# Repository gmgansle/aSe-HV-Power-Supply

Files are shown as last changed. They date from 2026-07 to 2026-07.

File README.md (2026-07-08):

# aSe-HV-Power-Supply
This repository includes all of the production files, SOPs, design contraints, and all other important information regarding the High Voltage power supply for use with a Inter-Digitated Electrode-based amorphous Selenium photodetector, or any other semiconducter that can be read using the Cremat CR150 and CR11x Charge Sensitive Preamplifers.

Though the board in it's current state may look complete, it is not. You will need to connect multiple ground pads to their respective pours, amongst other things. Make sure to run a DRC that comes back clean before generating output files.

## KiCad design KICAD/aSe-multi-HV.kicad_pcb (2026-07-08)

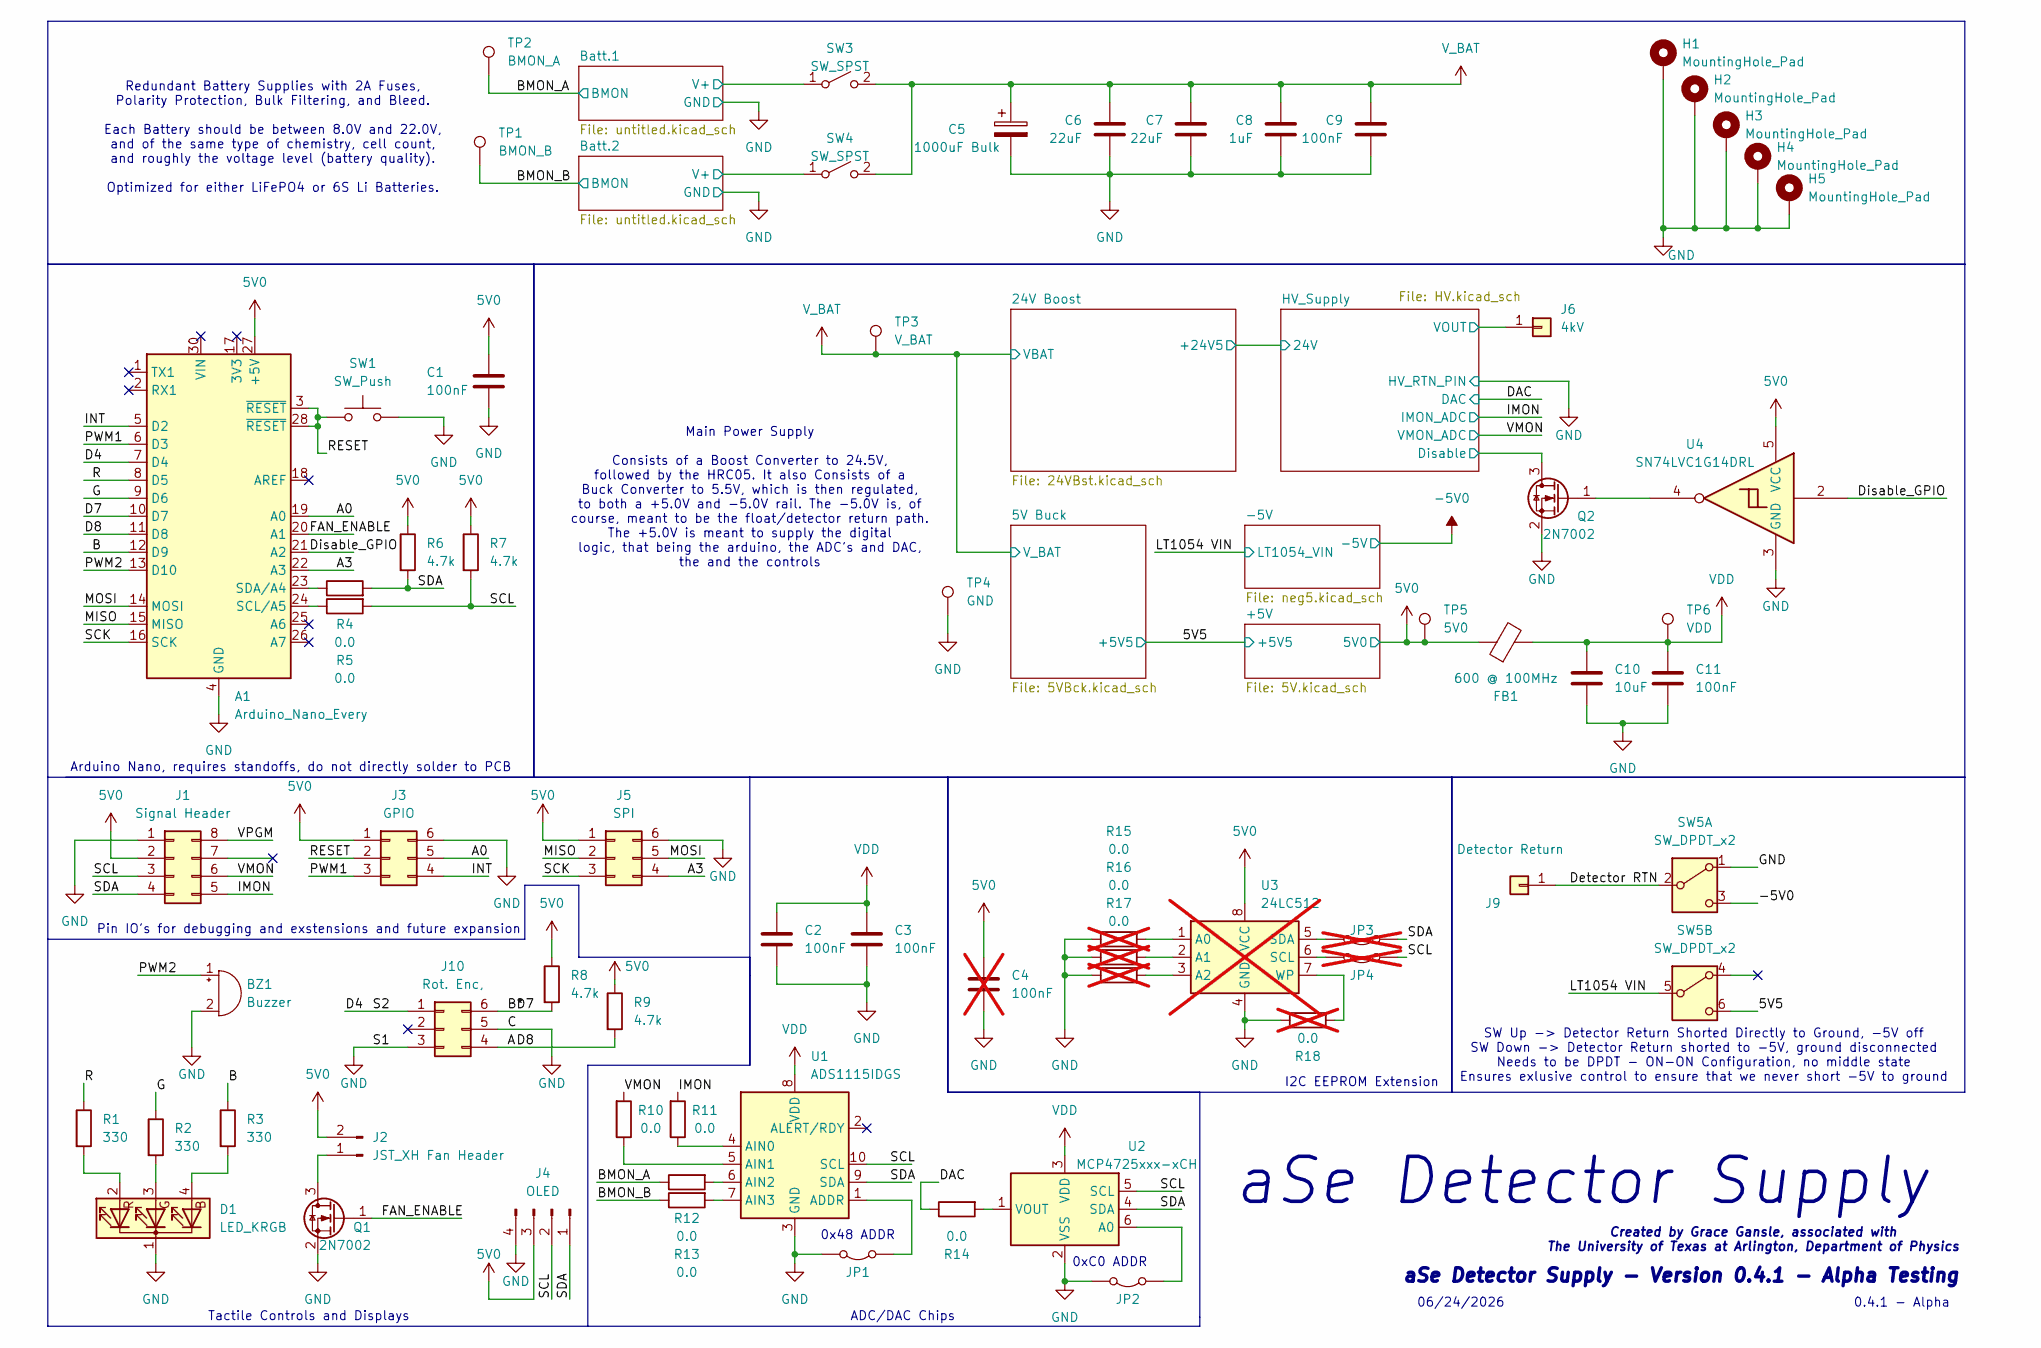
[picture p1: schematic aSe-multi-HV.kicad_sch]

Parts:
A1: Arduino_Nano_Every; Arduino_Nano
BZ1: Buzzer; PinSocket_1x02_P2.54mm_Vertical
C1, C2, C3, C9, C11: 100nF; C_1206_3216Metric_Pad1.33x1.80mm_HandSolder
C4: 100nF; C_1206_3216Metric_Pad1.33x1.80mm_HandSolder; not fitted
C5: 1000uF Bulk; CP_Radial_Tantal_D10.5mm_P5.00mm
C6, C7: 22uF; C_2220_5750Metric_Pad1.97x5.40mm_HandSolder
C8: 1uF; C_1206_3216Metric_Pad1.33x1.80mm_HandSolder
C10: 10uF; C_1206_3216Metric_Pad1.33x1.80mm_HandSolder
D1: LED_KRGB; PinSocket_2x02_P2.54mm_Vertical
FB1: 600 @ 100MHz; L_1206_3216Metric_Pad1.22x1.90mm_HandSolder
H1: MountingHole_Pad; MountingHole_2.2mm_M2_DIN965_Pad_TopBottom
H2, H3, H4, H5: MountingHole_Pad; MountingHole_2.2mm_M2_DIN965_Pad
J1: Signal Header; PinSocket_2x04_P2.54mm_Vertical
J2: JST_XH Fan Header; JST_XH_B2B-XH-AM_1x02_P2.50mm_Vertical
J3: GPIO; PinSocket_2x03_P2.54mm_Vertical
J4: OLED; PinSocket_1x04_P2.54mm_Vertical
J5: SPI; PinSocket_2x03_P2.54mm_Vertical
J6: 4kV; PinSocket_1x01_P2.54mm_Vertical
J9: Detector Return; PinSocket_1x01_P2.54mm_Vertical
J10: Rot. Enc,; PinSocket_2x03_P2.54mm_Vertical
JP1, JP2: SolderJumper-2_P1.3mm_Open_TrianglePad1.0x1.5mm
JP3, JP4: SolderJumper-2_P1.3mm_Open_TrianglePad1.0x1.5mm; not fitted
Q1, Q2: 2N7002; SOT-23
R1, R2, R3: 330; R_1206_3216Metric_Pad1.30x1.75mm_HandSolder
R4, R5, R10, R11, R12, R13, R14: 0.0; R_1206_3216Metric_Pad1.30x1.75mm_HandSolder
R6, R7, R8, R9: 4.7k; R_1206_3216Metric_Pad1.30x1.75mm_HandSolder
R15, R16, R17, R18: 0.0; R_1206_3216Metric_Pad1.30x1.75mm_HandSolder; not fitted
SW1: SW_Push; SW_PUSH_6mm_H5mm
SW3, SW4: SW_SPST; PinSocket_1x02_P2.54mm_Vertical
SW5: SW_DPDT_x2; PinSocket_2x03_P2.54mm_Vertical
TP1: BMON_B; TestPoint_Keystone_5000-5004_Miniature
TP2: BMON_A; TestPoint_Keystone_5000-5004_Miniature
TP3: V_BAT; TestPoint_Keystone_5000-5004_Miniature
TP4: GND; TestPoint_Keystone_5000-5004_Miniature
TP5: 5V0; TestPoint_Keystone_5000-5004_Miniature
TP6: VDD; TestPoint_Keystone_5000-5004_Miniature
U1: ADS1115IDGS; TSSOP-10_3x3mm_P0.5mm
U2: MCP4725xxx-xCH; SOT-23-6
U3: 24LC512; DIP-8_W7.62mm; not fitted
U4: SN74LVC1G14DRL; SOT-553

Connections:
5V0: A1.27 (+5V), C1.1, C4.1, FB1.1, J1.2, J2.2, J3.1, J4.3, J5.1, R6.1, R7.1, R8.1, R9.1, TP5.1 (1_1), U3.8 (VCC), U4.5 (VCC); also elsewhere on the board
-5V0: SW5.3 (C); also elsewhere on the board
/5V5: SW5.6 (C); also elsewhere on the board
/A: A1.11 (D8), J10.4, R9.2
/A0: A1.19 (A0), J3.5
/A3: A1.22 (A3), J5.4
/B: A1.12 (D9), R3.1
/B*: A1.10 (D7), J10.6, R8.2
/BMON_A: R12.1, TP2.1 (1_1); also elsewhere on the board
/BMON_B: R13.1, TP1.1 (1_1); also elsewhere on the board
/Batt.1/V+: SW3.1 (A); also elsewhere on the board
/Batt.2/V+: SW4.1 (A); also elsewhere on the board
/D4: A1.7 (D4), J10.1
/Detector RTN: J9.1 (Pin_1_1), SW5.2 (B)
/Disable_GPIO: A1.21 (A2), U4.2
/FAN_ENABLE: A1.20 (A1), Q1.1 (G)
/G: A1.9 (D6), R2.1
/HV_Supply/!Disable: Q2.3 (D); also elsewhere on the board
/HV_Supply/VOUT: J6.1 (Pin_1_1); also elsewhere on the board
/IMON: J1.5, R11.2; also elsewhere on the board
/INT: A1.5 (D2), J3.4
/LT1054 VIN: SW5.5 (B); also elsewhere on the board
/MISO: A1.15 (MISO), J5.2
/MOSI: A1.14 (MOSI), J5.5
/PWM1: A1.6 (D3), J3.3
/PWM2: A1.13 (D10), BZ1.1 (+)
/R: A1.8 (D5), R1.1
/RESET: A1.3 (~RESET), A1.28 (~RESET), J3.2, SW1.1
/SCK: A1.16 (SCK), J5.3
/SCL: J1.3, J4.2, JP4.1 (A), R5.2, R7.2, U1.10 (SCL), U2.5 (SCL)
/SDA: J1.4, J4.1, JP3.1 (A), R4.2, R6.2, U1.9 (SDA), U2.4 (SDA)
/VMON: J1.6, R10.2; also elsewhere on the board
/VPGM: J1.8, R14.1; also elsewhere on the board
GND: A1.4 (GND), A1.29 (GND), BZ1.2 (-), C1.2, C2.2, C3.2, C4.2, C5.2, C6.2, C7.2, C8.2, C9.2, C10.2, C11.2, D1.1 (K), H1.1 (1_1), H2.1 (1_1), H3.1 (1_1), H4.1 (1_1), H5.1 (1_1), J1.1, J3.6, J4.4, J5.6, J10.3, J10.5, JP1.2 (B), JP2.2 (B), Q1.2 (S), Q2.2 (S), R15.1, R16.1, R17.1, R18.2, SW1.2, SW5.1 (A), TP4.1 (1_1), U1.3 (GND), U2.2 (VSS), U3.4 (GND), U4.3 (GND); also elsewhere on the board
unnamed: A1.24 (SCL/A5), R5.1
unnamed: A1.23 (SDA/A4), R4.1
unnamed: D1.4 (BA), R3.2
unnamed: D1.3 (GA), R2.2
unnamed: D1.2 (RA), R1.2
unnamed: J2.1, Q1.3 (D)
unnamed: JP1.1 (A), U1.1 (ADDR)
unnamed: JP2.1 (A), U2.6 (A0)
unnamed: JP3.2 (B), U3.5 (SDA)
unnamed: JP4.2 (B), U3.6 (SCL)
unnamed: Q2.1 (G), U4.4
unnamed: R11.1, U1.4 (AIN0)
unnamed: R10.1, U1.5 (AIN1)
unnamed: R12.2, U1.6 (AIN2)
unnamed: R13.2, U1.7 (AIN3)
unnamed: R14.2, U2.1 (VOUT)
unnamed: R15.2, U3.1 (A0)
unnamed: R16.2, U3.2 (A1)
unnamed: R17.2, U3.3 (A2)
unnamed: R18.1, U3.7 (WP)
VDD: C2.1, C3.1, C10.1, C11.1, FB1.2, TP6.1 (1_1), U1.8 (VDD), U2.3 (VDD)
V_BAT: C5.1, C6.1, C7.1, C8.1, C9.1, SW3.2 (B), SW4.2 (B), TP3.1 (1_1); also elsewhere on the board

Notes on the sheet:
0x48 ADDR
0.4.1 - Alpha
SW Up -> Detector Return Shorted Directly to Ground, -5V off SW Down -> Detector Return shorted to -5V, ground disconnected Needs to be DPDT - ON-ON Configuration, no middle state Ensures exlusive control to ensure that we never short -5V to ground
Created by Grace Gansle, associated with The University of Texas at Arlington, Department of Physics
ADC/DAC Chips
aSe Detector Supply
Arduino Nano, requires standoffs, do not directly solder to PCB
0xC0 ADDR
Tactile Controls and Displays
06/24/2026
Redundant Battery Supplies with 2A Fuses, Polarity Protection, Bulk Filtering, and Bleed. Each Battery should be between 8.0V and 22.0V, and of the same type of chemistry, cell count, and roughly the voltage level (battery quality). Optimized for either LiFePO4 or 6S Li Batteries.
aSe Detector Supply - Version 0.4.1 - Alpha Testing
I2C EEPROM Extension
Pin IO's for debugging and exstensions and future expansion
Main Power Supply Consists of a Boost Converter to 24.5V, followed by the HRC05. It also Consists of a Buck Converter to 5.5V, which is then regulated, to both a +5.0V and -5.0V rail. The -5.0V is, of course, meant to be the float/detector return path. The +5.0V is meant to supply the digital logic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

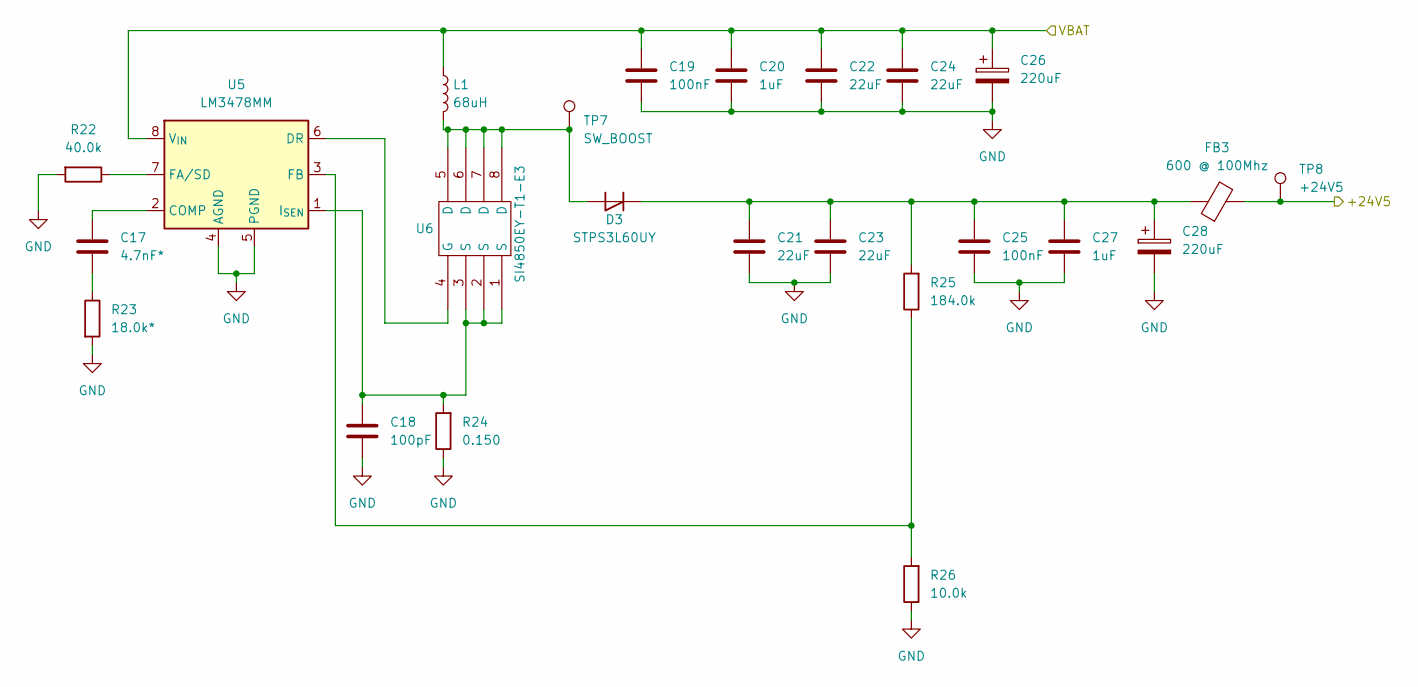
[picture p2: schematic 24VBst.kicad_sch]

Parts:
C17: 4.7nF*; C_1206_3216Metric_Pad1.33x1.80mm_HandSolder
C18: 100pF; C_1206_3216Metric_Pad1.33x1.80mm_HandSolder
C19, C25: 100nF; C_1206_3216Metric_Pad1.33x1.80mm_HandSolder
C20, C27: 1uF; C_1206_3216Metric_Pad1.33x1.80mm_HandSolder
C21, C22, C23, C24: 22uF; C_2220_5750Metric_Pad1.97x5.40mm_HandSolder
C26, C28: 220uF; CP_Radial_Tantal_D10.5mm_P5.00mm
D3: STPS3L60UY; D_SMB-SMC_Universal_Handsoldering
FB3: 600 @ 100Mhz; L_1206_3216Metric_Pad1.22x1.90mm_HandSolder
L1: 68uH; L_Coilcraft_MSS1260-XXX
R22: 40.0k; R_1206_3216Metric_Pad1.30x1.75mm_HandSolder
R23: 18.0k*; R_1206_3216Metric_Pad1.30x1.75mm_HandSolder
R24: 0.150; R_1206_3216Metric_Pad1.30x1.75mm_HandSolder
R25: 184.0k; R_1206_3216Metric_Pad1.30x1.75mm_HandSolder
R26: 10.0k; R_1206_3216Metric_Pad1.30x1.75mm_HandSolder
TP7: SW_BOOST; TestPoint_Keystone_5000-5004_Miniature
TP8: +24V5; TestPoint_Keystone_5000-5004_Miniature
U5: LM3478MM; VSSOP-8_3x3mm_P0.65mm
U6: SI4850EY-T1-E3; SOIC-8_3.9x4.9mm_P1.27mm

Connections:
/24V Boost/+24V5: FB3.2, TP8.1 (1_1); also elsewhere on the board
GND: C18.2, C19.2, C20.2, C21.2, C22.2, C23.2, C24.2, C25.2, C26.2, C27.2, C28.2, R22.2, R23.2, R24.1, R26.1, U5.4 (AGND), U5.5 (PGND); also elsewhere on the board
unnamed: C17.1, R23.1
unnamed: D3.2 (A), L1.2, TP7.1 (1_1), U6.5 (D), U6.6 (D), U6.7 (D), U6.8 (D)
unnamed: C21.1, C23.1, C25.1, C27.1, C28.1, D3.1 (K), FB3.1, R25.2
unnamed: C17.2, U5.2 (COMP)
unnamed: U5.6 (DR), U6.4 (G)
unnamed: R22.1, U5.7 (FA/SD)
unnamed: R25.1, R26.2, U5.3 (FB)
unnamed: C18.1, R24.2, U5.1 (I_{SEN}), U6.1 (S), U6.2 (S), U6.3 (S)
V_BAT: C19.1, C20.1, C22.1, C24.1, C26.1, L1.1, U5.8 (V_{IN}); also elsewhere on the board

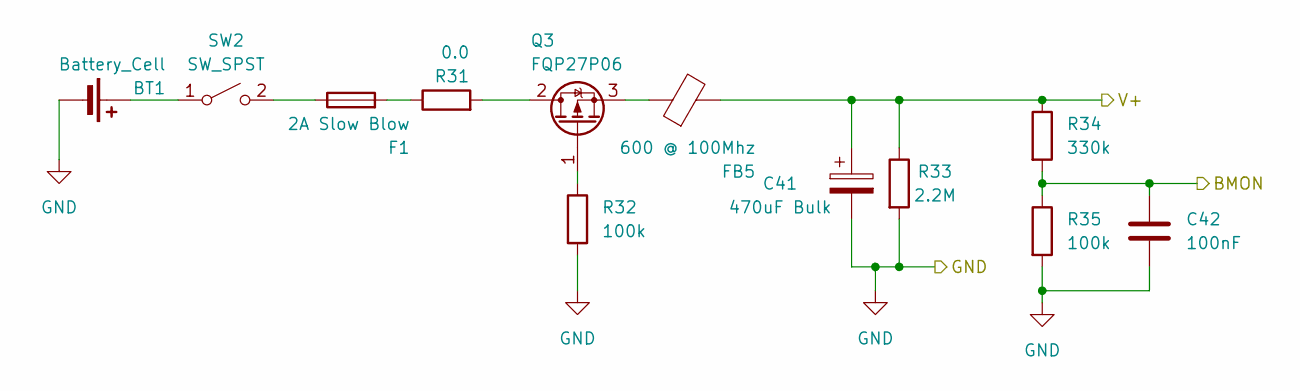
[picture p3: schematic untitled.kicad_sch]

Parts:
BT1: Battery_Cell; JST_XH_B2B-XH-AM_1x02_P2.50mm_Vertical
C41: 470uF Bulk; CP_Radial_Tantal_D10.5mm_P5.00mm
C42: 100nF; C_1206_3216Metric_Pad1.33x1.80mm_HandSolder
F1: 2A Slow Blow; Fuseholder_Littelfuse_100_series_5x20mm
FB5: 600 @ 100Mhz; L_1206_3216Metric_Pad1.22x1.90mm_HandSolder
Q3: FQP27P06; TO-220-3_Vertical
R31: 0.0; R_1206_3216Metric_Pad1.30x1.75mm_HandSolder
R32, R35: 100k; R_1206_3216Metric_Pad1.30x1.75mm_HandSolder
R33: 2.2M; R_1206_3216Metric_Pad1.30x1.75mm_HandSolder
R34: 330k; R_1206_3216Metric_Pad1.30x1.75mm_HandSolder
SW2: SW_SPST; PinSocket_1x02_P2.54mm_Vertical

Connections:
/BMON_B: C42.1, R34.2, R35.1; also elsewhere on the board
/Batt.2/V+: C41.1, FB5.2, R33.1, R34.1; also elsewhere on the board
GND: BT1.2 (-), C41.2, C42.2, R32.2, R33.2, R35.2; also elsewhere on the board
unnamed: BT1.1 (+), SW2.1 (A)
unnamed: F1.2, R31.1
unnamed: Q3.2 (D), R31.2
unnamed: Q3.1 (G), R32.1
unnamed: FB5.1, Q3.3 (S)
unnamed: F1.1, SW2.2 (B)

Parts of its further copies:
BT2: Battery_Cell; JST_XH_B2B-XH-AM_1x02_P2.50mm_Vertical
C58: 470uF Bulk; CP_Radial_Tantal_D10.5mm_P5.00mm
C59: 100nF; C_1206_3216Metric_Pad1.33x1.80mm_HandSolder
F2: 2A Slow Blow; Fuseholder_Littelfuse_100_series_5x20mm
FB7: 600 @ 100Mhz; L_1206_3216Metric_Pad1.22x1.90mm_HandSolder
Q4: FQP27P06; TO-220-3_Vertical
R36: 0.0; R_1206_3216Metric_Pad1.30x1.75mm_HandSolder
R37, R40: 100k; R_1206_3216Metric_Pad1.30x1.75mm_HandSolder
R38: 2.2M; R_1206_3216Metric_Pad1.30x1.75mm_HandSolder
R39: 330k; R_1206_3216Metric_Pad1.30x1.75mm_HandSolder
SW6: SW_SPST; PinSocket_1x02_P2.54mm_Vertical

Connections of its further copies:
/BMON_A: C59.1, R39.2, R40.1; also elsewhere on the board
/Batt.1/V+: C58.1, FB7.2, R38.1, R39.1; also elsewhere on the board
GND: BT2.2 (-), C58.2, C59.2, R37.2, R38.2, R40.2; also elsewhere on the board
unnamed: BT2.1 (+), SW6.1 (A)
unnamed: F2.2, R36.1
unnamed: Q4.2 (D), R36.2
unnamed: Q4.1 (G), R37.1
unnamed: FB7.1, Q4.3 (S)
unnamed: F2.1, SW6.2 (B)

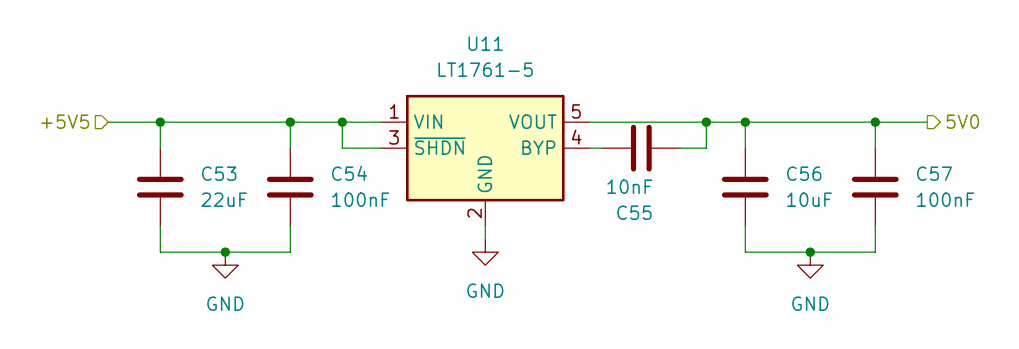
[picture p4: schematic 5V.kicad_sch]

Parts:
C53: 22uF; C_2220_5750Metric_Pad1.97x5.40mm_HandSolder
C54, C57: 100nF; C_1206_3216Metric_Pad1.33x1.80mm_HandSolder
C55: 10nF; C_1206_3216Metric_Pad1.33x1.80mm_HandSolder
C56: 10uF; C_2220_5750Metric_Pad1.97x5.40mm_HandSolder
U11: LT1761-5; TSOT-23-5

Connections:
5V0: C55.2, C56.1, C57.1, U11.5 (VOUT); also elsewhere on the board
/5V5: C53.1, C54.1, U11.1 (VIN), U11.3 (~SHDN); also elsewhere on the board
GND: C53.2, C54.2, C56.2, C57.2, U11.2 (GND); also elsewhere on the board
unnamed: C55.1, U11.4 (BYP)

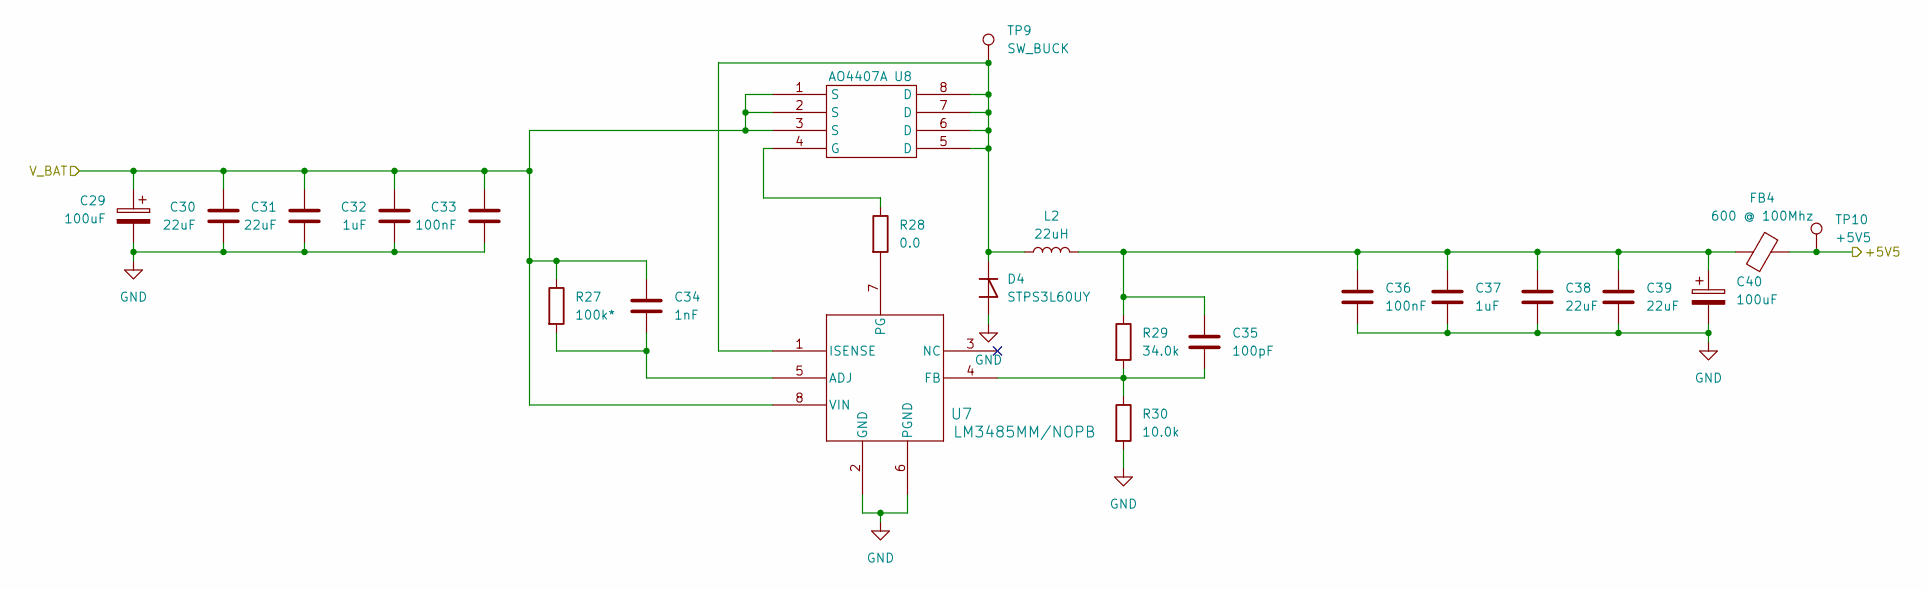
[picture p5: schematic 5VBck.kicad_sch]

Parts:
C29, C40: 100uF; CP_Radial_Tantal_D10.5mm_P5.00mm
C30, C31, C38, C39: 22uF; C_2220_5750Metric_Pad1.97x5.40mm_HandSolder
C32, C37: 1uF; C_1206_3216Metric_Pad1.33x1.80mm_HandSolder
C33, C36: 100nF; C_1206_3216Metric_Pad1.33x1.80mm_HandSolder
C34: 1nF; C_1206_3216Metric_Pad1.33x1.80mm_HandSolder
C35: 100pF; C_1206_3216Metric_Pad1.33x1.80mm_HandSolder
D4: STPS3L60UY; D_SMB-SMC_Universal_Handsoldering
FB4: 600 @ 100Mhz; L_1206_3216Metric_Pad1.22x1.90mm_HandSolder
L2: 22uH; L_Coilcraft_MSS1260-XXX
R27: 100k*; R_1206_3216Metric_Pad1.30x1.75mm_HandSolder
R28: 0.0; R_1206_3216Metric_Pad1.30x1.75mm_HandSolder
R29: 34.0k; R_1206_3216Metric_Pad1.30x1.75mm_HandSolder
R30: 10.0k; R_1206_3216Metric_Pad1.30x1.75mm_HandSolder
TP9: SW_BUCK; TestPoint_Keystone_5000-5004_Miniature
TP10: +5V5; TestPoint_Keystone_5000-5004_Miniature
U7: LM3485MM/NOPB; VSSOP-8_3x3mm_P0.65mm
U8: AO4407A; SOIC-8_3.9x4.9mm_P1.27mm

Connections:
/5V5: FB4.2, TP10.1 (1_1); also elsewhere on the board
GND: C29.2, C30.2, C31.2, C32.2, C33.2, C36.2, C37.2, C38.2, C39.2, C40.2, D4.2 (A), R30.2, U7.2 (GND), U7.6 (PGND); also elsewhere on the board
unnamed: C35.1, C36.1, C37.1, C38.1, C39.1, C40.1, FB4.1, L2.2, R29.1
unnamed: D4.1 (K), L2.1, TP9.1 (1_1), U7.1 (ISENSE), U8.5 (D), U8.6 (D), U8.7 (D), U8.8 (D)
unnamed: C34.2, R27.2, U7.5 (ADJ)
unnamed: C35.2, R29.2, R30.1, U7.4 (FB)
unnamed: R28.2, U7.7 (PG)
unnamed: R28.1, U8.4 (G)
V_BAT: C29.1, C30.1, C31.1, C32.1, C33.1, C34.1, R27.1, U7.8 (VIN), U8.1 (S), U8.2 (S), U8.3 (S); also elsewhere on the board

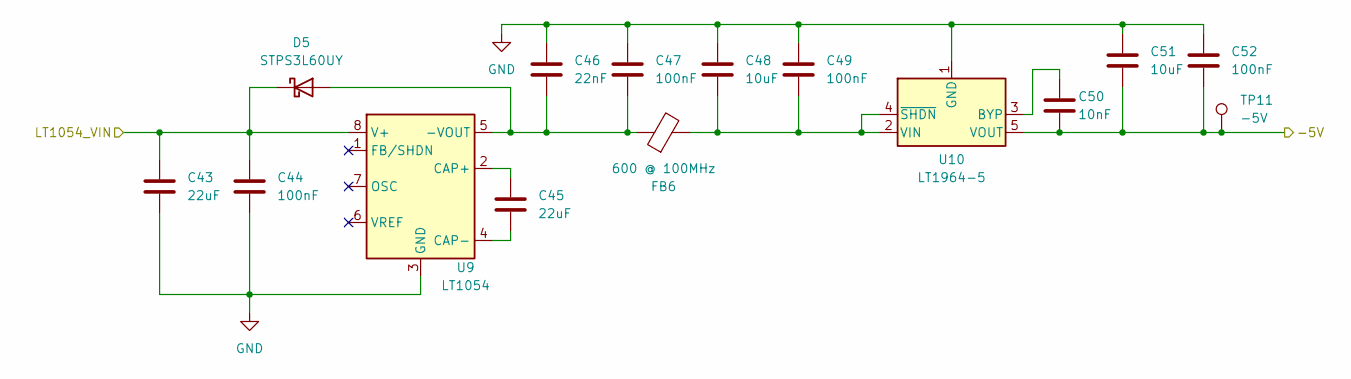
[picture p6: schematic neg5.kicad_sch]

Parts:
C43, C45: 22uF; C_2220_5750Metric_Pad1.97x5.40mm_HandSolder
C44, C47, C49, C52: 100nF; C_1206_3216Metric_Pad1.33x1.80mm_HandSolder
C46: 22nF; C_1206_3216Metric_Pad1.33x1.80mm_HandSolder
C48, C51: 10uF; C_2220_5750Metric_Pad1.97x5.40mm_HandSolder
C50: 10nF; C_1206_3216Metric_Pad1.33x1.80mm_HandSolder
D5: STPS3L60UY; D_SMB-SMC_Universal_Handsoldering
FB6: 600 @ 100MHz; L_1206_3216Metric_Pad1.22x1.90mm_HandSolder
TP11: -5V; TestPoint_Keystone_5000-5004_Miniature
U9: LT1054; DIP-8_W7.62mm_Socket
U10: LT1964-5; TSOT-23-5

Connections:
-5V0: C50.2, C51.2, C52.2, TP11.1 (1_1), U10.5 (VOUT); also elsewhere on the board
/LT1054 VIN: C43.1, C44.1, D5.1 (K), U9.8 (V+); also elsewhere on the board
GND: C43.2, C44.2, C46.1, C47.1, C48.1, C49.1, C51.1, C52.1, U9.3 (GND), U10.1 (GND); also elsewhere on the board
unnamed: C46.2, C47.2, D5.2 (A), FB6.1, U9.5 (-VOUT)
unnamed: C45.1, U9.2 (CAP+)
unnamed: C45.2, U9.4 (CAP-)
unnamed: C50.1, U10.3 (BYP)
unnamed: C48.2, C49.2, FB6.2, U10.2 (VIN), U10.4 (~SHDN)

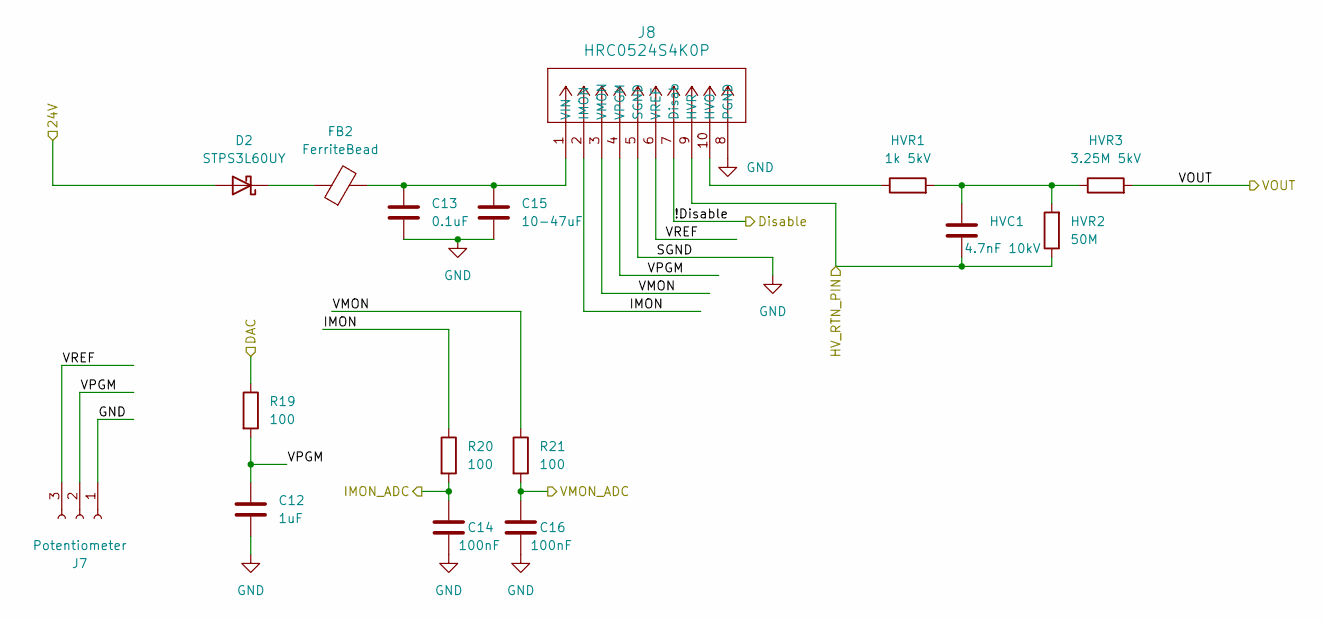
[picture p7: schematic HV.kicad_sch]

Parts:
C12: 1uF; C_1206_3216Metric_Pad1.33x1.80mm_HandSolder
C13: 0.1uF; C_1206_3216Metric_Pad1.33x1.80mm_HandSolder
C14, C16: 100nF; C_1206_3216Metric_Pad1.33x1.80mm_HandSolder
C15: 10-47uF; C_1206_3216Metric_Pad1.33x1.80mm_HandSolder
D2: STPS3L60UY; D_SMB-SMC_Universal_Handsoldering
FB2: FerriteBead; L_1206_3216Metric_Pad1.22x1.90mm_HandSolder
HVC1: 4.7nF 10kV; C_Disc_D16.0mm_W5.0mm_P10.00mm
HVR1: 1k 5kV; R_Axial_DIN0207_L6.3mm_D2.5mm_P15.24mm_Horizontal
HVR2: 50M; R_Axial_DIN0207_L6.3mm_D2.5mm_P15.24mm_Horizontal
HVR3: 3.25M 5kV; R_Axial_DIN0207_L6.3mm_D2.5mm_P15.24mm_Horizontal
J7: Potentiometer; PinSocket_1x03_P2.54mm_Vertical
J8: HRC0524S4K0P; CONN10_4S4K0N_XPP
R19, R20, R21: 100; R_1206_3216Metric_Pad1.30x1.75mm_HandSolder

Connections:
/24V Boost/+24V5: D2.2 (A); also elsewhere on the board
/HV_Supply/!Disable: J8.7 (Disab); also elsewhere on the board
/HV_Supply/IMON: J8.2 (IMON), R20.1
/HV_Supply/VMON: J8.3 (VMON), R21.1
/HV_Supply/VOUT: HVR3.2; also elsewhere on the board
/HV_Supply/VPGM: C12.1, J7.2, J8.4 (VPGM), R19.2
/HV_Supply/VREF: J7.3, J8.6 (VREF)
/IMON: C14.1, R20.2; also elsewhere on the board
/VMON: C16.1, R21.2; also elsewhere on the board
/VPGM: R19.1; also elsewhere on the board
GND: C12.2, C13.2, C14.2, C15.2, C16.2, HVC1.2, HVR2.1, J7.1, J8.5 (SGND), J8.8 (PGND), J8.9 (HVR); also elsewhere on the board
unnamed: D2.1 (K), FB2.1
unnamed: HVC1.1, HVR1.2, HVR2.2, HVR3.1
unnamed: HVR1.1, J8.10 (HVO)
unnamed: C13.1, C15.1, FB2.2, J8.1 (VIN)

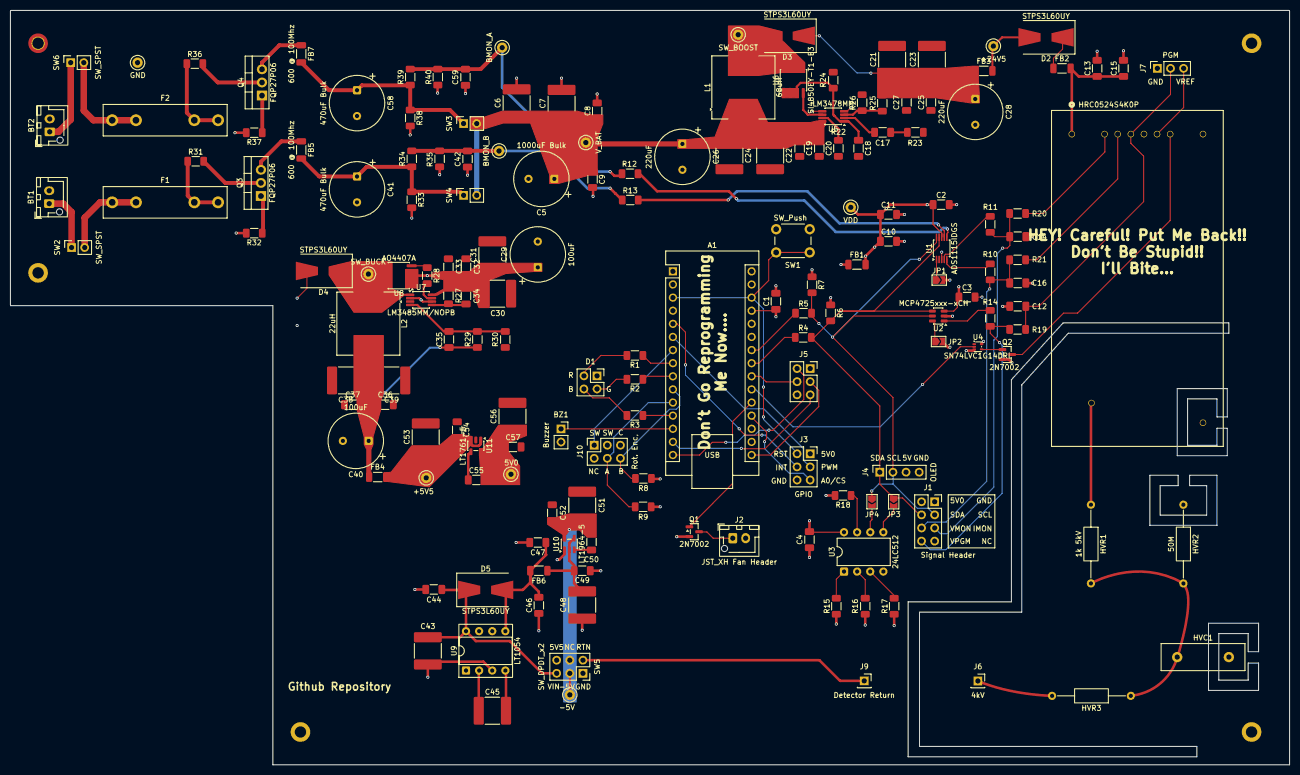
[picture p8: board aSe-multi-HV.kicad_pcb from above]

Board: 4 copper layers, 247.7 x 146.1 mm, 174 parts (0 on the bottom side), 97 nets.

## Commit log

2026-07-08 Create KICAD
2026-07-08 Update README with board status and DRC instructions
    Added important notes about board completion and DRC checks.
